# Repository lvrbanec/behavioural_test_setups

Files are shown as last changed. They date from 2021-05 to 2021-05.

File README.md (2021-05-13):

# Behavioural test setups

Behavioural tests setups created to test cognitive abilities of wild shrews (Sorex araneus).
Setups were modelled FreeCAD and automatized with Arduino and Raspberry Pi. 

Here I provide the 3D modells as well as the code.

** Half of the setups where created at the Max Planck Insitute (MPI) for Animal Behavior (Radolfzell, Germany) and therefore, belong to this insitution. For reuse of setup in research or industry please acquire consensus from MPI.

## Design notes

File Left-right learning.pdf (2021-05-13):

# Explanation of the left-right learning setup for testing cognitive abilities of common shrews (Sorex araneus)

### Author: Lara Vrbanec

### Date: 30.10.2020

# Contents

## Objective

The objective of the left- right learning setup is to test the spatial memory of the common shrew in the outside enclosure, without the disturbance of the experimenter. The animal is presented with two identical opaque tunnels, one of which always provides the food reward. The aim is to see how many trials animal needs to learn the rewarding arm, and how high is the mistake (how often the animal will sample the non-rewarding arm) after the learning objective is reached.

## Left right learning setup design

Setup consist of two identical opaque tunnels (1 x 10cm) connected to the automatic food dispenser. Every tube consists of two IR sensors, which record the direction of animal movement (entry / exit), and date and time of the activation. The information is saved as a .txt file on a SD card as ' sensor,1a,timestamp,[date].

## Tunnel design

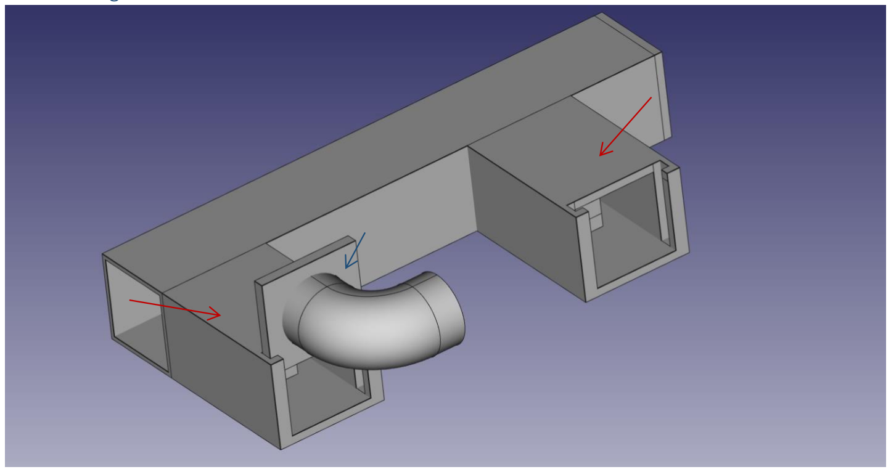
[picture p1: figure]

Figure 1. 3D model of the right / left tunnel created in software FreeCAD. Two constructions on the right marked with red arrows are used as IR sensor holders, and for the stabilization of the test setup. The lid, marked with blue arrow is used to prevent the moisture from entering the setup as the setup is intended for use in outdoor conditions.

## Automatic food dispenser design

The dispenser consists of thee parts (i) body that holds the mealworms (ii) casing and (iii) lid. The body is intended to connect to the NEMA-17 size stepper motor, which allows for the rotation of the dispenser and the dispensing of mealworms due to the gravity.

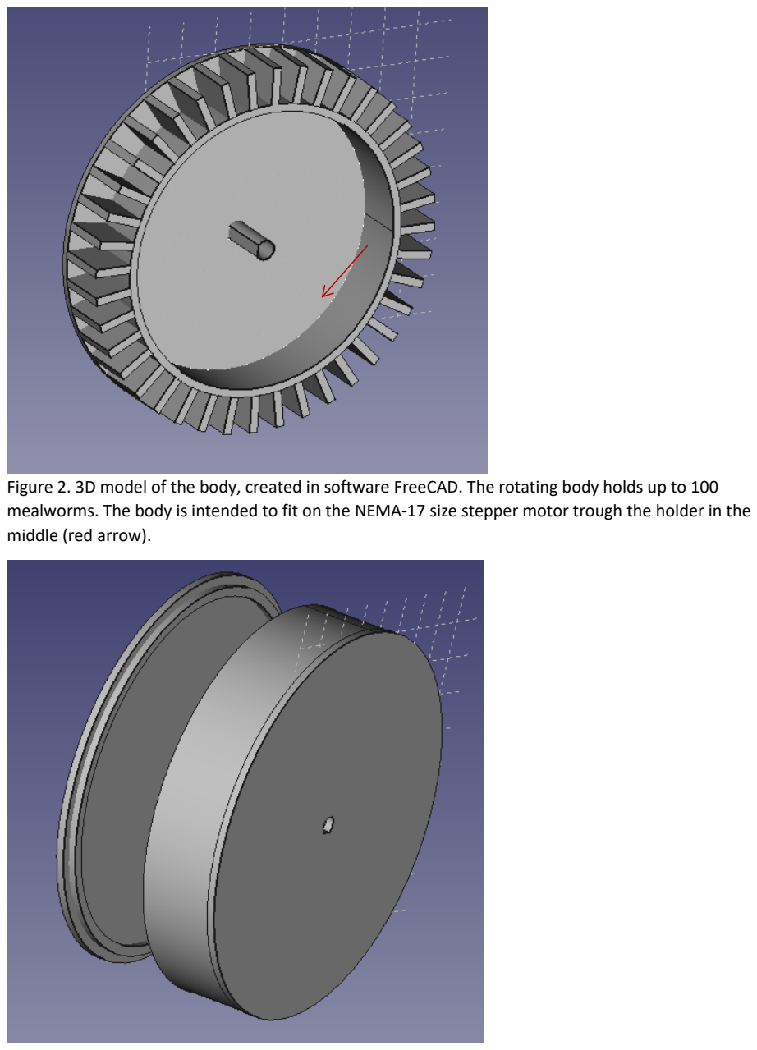
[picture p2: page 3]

Figure 2. 3D model of the body, created in software FreeCAD. The rotating body holds up to 100 mealworms. The body is intended to fit on the NEMA-17 size stepper motor trough the holder in the middle (red arrow).

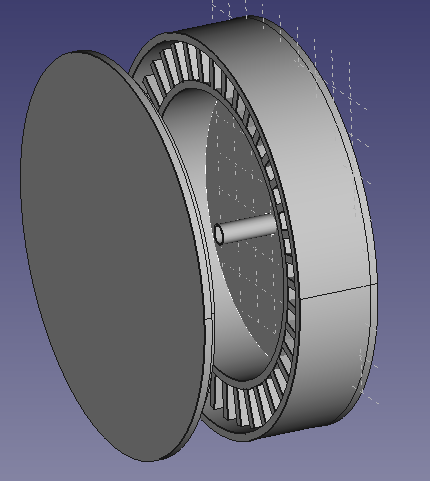
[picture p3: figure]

Figure 4. 3D model of the whole food dispenser, created in software FreeCAD.

## Electronics components and Supplies

### - 1x Arduino (we used Arduino Uno)

### - 1x Adafruit Motor Shield V2

### - 4x obstacle avoidance IR sensors (we used Waveshare)

### - 1x stepper motor (we used NEMA-17 size - 200 steps/rev, 12V 350mA)

### - RTC for Arduino (we used tiny RTC I2C module)

### - Micro SD card module

### - Bread board

### - Jumper cables

- Power source for Arduino (we used 12V/5A) and for Raspberry Pi (we used official SUB charger 5.1V 3A)

### - micro SD card

## Schematics

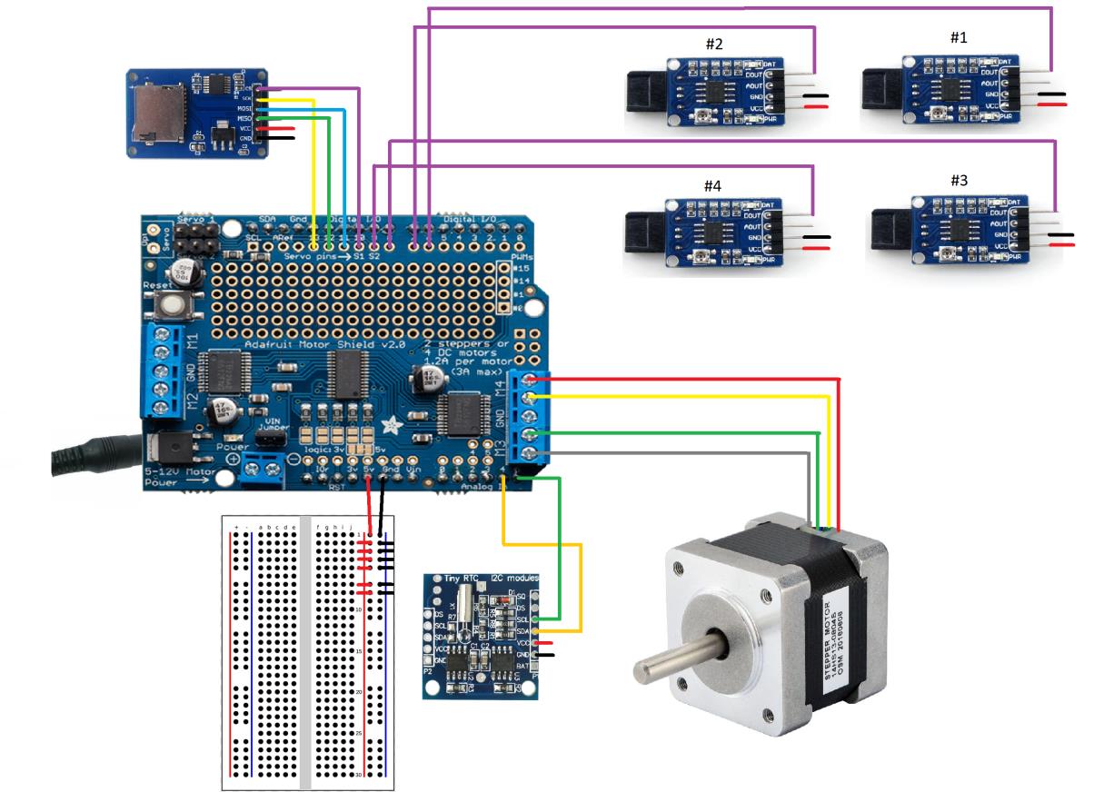
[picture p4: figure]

## Arduino code

When the animal enters the tunnel (sensor2 activated after sensor1) the motor dispenses the food and saves the unix time of animal entrance on the SD card.

// OS Windows 10, Arduino 1.8.10

// Author Lara Vrbanec

// Date 06/04/2020

// code sources SD_card https://lastminuteengineers.com/arduino-microsd-card-module-tutorial/ RTC https://lastminuteengineers.com/ds1307-rtc-arduino-tutorial/

// sensors Waveshare_IR_sensor MicroSD_card_adapter Tiny_RTC_12C_module(DS1307)

// When IR sensor1 is activated after IR sensor2, the motor is rotated and the unix time is saved on a micro SD card

// When IR sensor3 is activated after IR sensor4, the unix time is saved on SD card

#include <SPI.h> | // library for SPI SD

#include <SD.h> | // library for SD

#include <Wire.h> // library for RTC

#include "RTClib.h" // library RTClib by Adafruit for RTC

#include <Adafruit_MotorShield.h> // library for Adafruit motor shield v2

#define ledPin 4

#define motor 2

#define IR1 6

#define IR2 7

#define IR3 8

#define IR4 9

RTC_DS1307 rtc;

File myFile; // name of a file to be saved

Adafruit_MotorShield AFMS = Adafruit_MotorShield(); // Create the motor shield object with the default I2C address

Adafruit_StepperMotor *Motor = AFMS.getStepper(200, motor); // Connect a stepper North with 200 steps per revolution (1.8 degree) to motor port #2 (M3 and M4)

const int chipSelect = 10; // SD of SD card module. Other SD pins are pre-defined

const int OneMotorRotation = 15; // define n degrees by which the motor will move

boolean seq1 = false; // used to create a sequence of sensors

boolean seq2 = false; // used to create a sequence of sensors

// blink out an error code (number of blinks equal the error number)

void error(uint8_t errno) {

while(1) {

uint8_t i;

for (i=0; i<errno; i++) {

digitalWrite(ledPin, HIGH);

delay(100);

digitalWrite(ledPin, LOW);

delay(100);

}

for (i=errno; i<10; i++) {

delay(200);

}

}

}

void setup()

{

// Open serial communications

Serial.begin(9600);

// create with the default frequency 1.6KHz for motor shield

AFMS.begin();

// Define IR sensor imput (digital)

pinMode(IR1,INPUT); //

pinMode(IR2,INPUT); //

pinMode(IR3,INPUT); //

pinMode(IR4,INPUT); //

// Set speed of motor

Motor -> setSpeed(20); // 10 rpm

// Check if SD card started normally

Serial.print("Initializing SD card...");

if (!SD.begin()) {

Serial.println("initialization failed!");

error(1);

return;

}

Serial.println("initialization done.");

// Create a filename on SD when Arduino re-starts

char filename[15]; //create a filename with 15 characters

strcpy(filename, "TRC00.TXT");

for (uint8_t i = 0; i < 100; i++) {

filename[3] = '0' + i/10;

filename[4] = '0' + i%10;

if (! SD.exists(filename)) {

// only open a new file if it doesn't exist

myFile = SD.open(filename, FILE_WRITE);

// write if it cannot open the SD

if( ! myFile ) {

Serial.print("Couldnt create ");

Serial.println(filename);

error(2);

return; //try again the loop

}

Serial.print("Opened ");

Serial.println(filename);

break; // leave the loop!

}

}

// Check if RTC started normally

Serial.print("Initializing RTC...");

if (! rtc.begin()) {

Serial.println("Couldn't find RTC");

error(3);

while (1);

}

if (!rtc.isrunning()) {

Serial.println("RTC lost power, lets set the time!");

// Comment out below lines once you set the date & time.

// Following line sets the RTC to the date & time this sketch was compiled

// rtc.adjust(DateTime(F(__DATE__), F(__TIME__))); //uncomment if you want to set the time

// Following line sets the RTC with an explicit date & time

// for example to set January 27 2017 at 12:56 you would call:

// rtc.adjust(DateTime(2017, 1, 27, 12, 56, 0));

}

Serial.println("initialization done.");

}

void loop()

{

//if the animal choses correct side

if (digitalRead(IR1)==0) {

seq1 = true;

Serial.println("Sensor IR1 detected movement");

}

if (seq1 == true && digitalRead(IR2)==0) { // if BOTH

Serial.println("Sensor IR2 detected movement after IR1");

// move motor

Motor->step(OneMotorRotation, FORWARD , SINGLE); // 50 is 90 degrees as the motor has 200 steps

// get the unix time

DateTime currentTime = rtc.now();

// if the file opened okay, write to it:

if (myFile) {

Serial.println("writing to txt file...");

myFile.print("Choice,true,"); myFile.print("Timestamp,");

myFile.println(currentTime.unixtime()); //write to SD

myFile.flush(); // without .flush nothing can be printed on a card

}

if (! myFile) {

error(4);

return;

}

seq1 = false;

}

//if the animal choses wrong side

if (digitalRead(IR3)==0) {

seq2 = true;

Serial.println("Sensor IR3 detected movement");

}

if (seq2 == true && digitalRead(IR4)==0) { // if BOTH

Serial.println("Sensor IR4 detected movement after IR3");

// get the unix time

DateTime currentTime = rtc.now();

// if the file opened okay, write to it:

if (myFile) {

Serial.println("writing to txt file...");

myFile.print("Choice,false,"); myFile.print("Timestamp,");

myFile.println(currentTime.unixtime()); //write to SD

myFile.flush(); // without .flush nothing can be printed on a card

}

if (! myFile) {

error(4);

return;

}

seq2 = false;

}

}

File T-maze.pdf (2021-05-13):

# Guidance for using automated multiple T maze designed to test cognitive abilities of common shrews (Sorex araneus)

Owner: Max Planck Institute for Animal Behavior

Author: Lara Vrbanec

Date: 19.05.2020

## Contents

### Objective

The aim of the multiple T maze is to test common shrews’ navigation abilities related to foraging. The animal which makes less mistakes to learn the path which leads to a food reward is considered to be superior in navigation.

### Multiple T maze design

Maze arms are built from the opaque grey plastics and covered by the transparent Plexiglas®. The dimension of each arm was 100 x 5 x 5 cm (length, with, height). The maze can be placed into two configurations which are the left - right mirror images of each other. In the first configuration the animal has to perform the sequence of R, L, L, R, R, L turns to escape the maze. In the second configuration has to perform the sequence of L, R, R, L, L, R turns to escape the maze.
As our goal is to test animal’s navigation abilities related to foraging, the escaping arm is reinforced with a food reward. In order to simulate natural environment, maze floor is covered with the white sand. The entrance and the goal arm of the maze is connected with the home cage with transparent tubes. The setup includes two automatic doors and one automatic food dispenser. The first automatic door (in the following text referred to as the South door) is placed at the entrance of the maze. The second door (in the following text referred to as the North door) is placed 20 cm in front the food reward. First pair of movement sensors (in the following text referred to as the South sensor) are placed few centimeters behind the South door. The second pair of movement sensors (in the following text referred to as the North sensors) are placed few centimeters being the North door. The automatic feeder is positioned at the end of the goal arm and is used for automatic refill of food award.

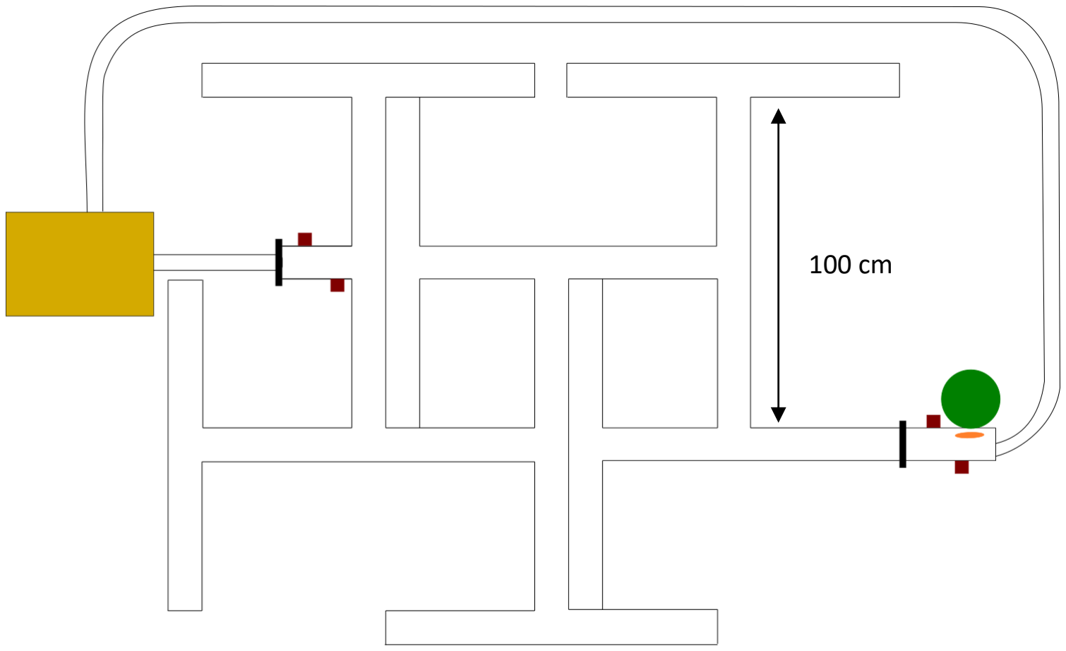
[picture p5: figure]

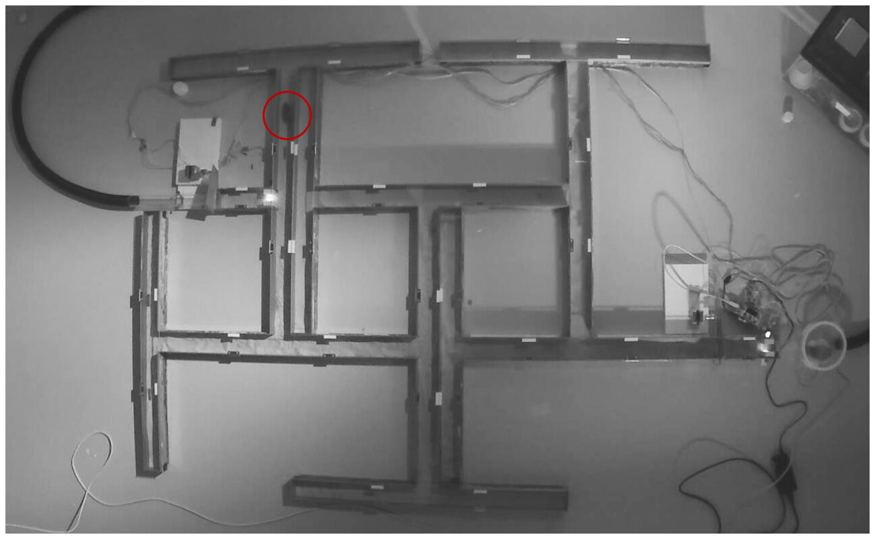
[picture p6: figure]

Figure 2. Upper image: Schematic of the multiple T maze in the first configuration (R, L, L, R, R, L ). Home cage is shown in yellow, automatic doors in black, movement sensors in red, automatic food dispenser in green, and food reward (mealworm) in orange. Lower image: multiple T maze under low light, recorded with IR camera. The position of the animal is shown with the red circle.

Automatic doors design
A stepper motor arm was prolonged with a screw over motor coupling. Onto prolonged arm, using two mothers, we attached an opaque Plexiglas sheet (2mm thickness, 15 cm length, 7 cm height). Rotation of the motor arm caused rotation of the Plexiglas sheet.

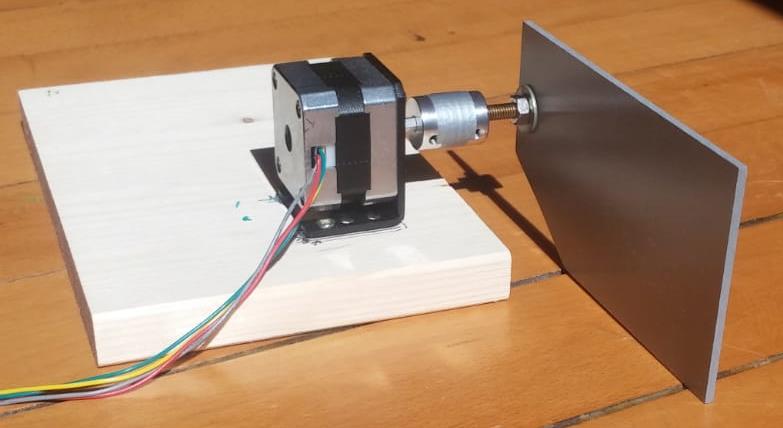
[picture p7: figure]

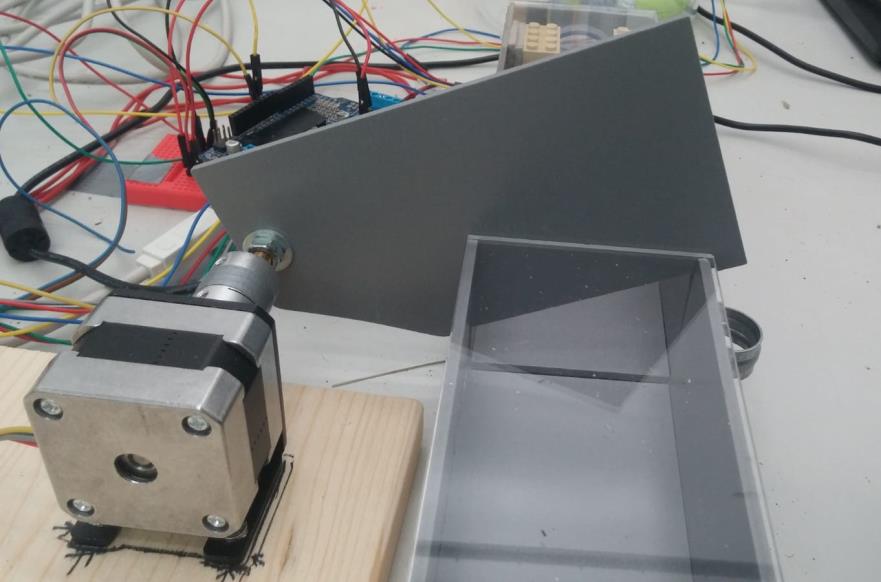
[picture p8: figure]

Figure 3. Automatic doors.

Automatic food dispenser design
Automatic food dispenser was built from the manual pill dispenser (example of a pill dispenser https://www.amazon.co.uk/Aidapt-Compact-Weekday-Dispenser-Eligible/dp/B0079N7L8U) by replacing the mechanism for manual rotation with a stepper motor.

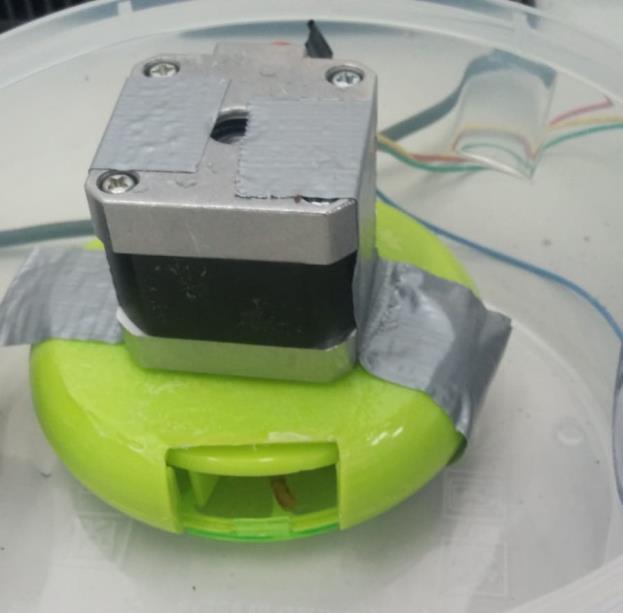
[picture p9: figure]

Figure 4. Automatic food dispenser

IR movement sensors design

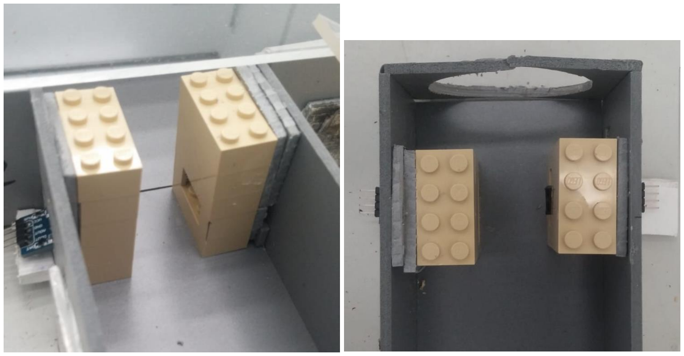
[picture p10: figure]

Figure 5. IR movement sensors placed at the beginning and the end of the labyrinth. The structure is L-R symmetrical so the animal cannot use sensor as cue for orientation.

### The logic behind the code

When the Arduino Uno reboots, the South doors open, which allows animal to enter the multiple T maze. Animal’s entrance in the multiple T maze triggers the South IR movement sensor, which causes automatic feeder to drop the food and the North door to open. When the animal enters the goal arm of the maze and triggers North IR movement sensor, both the North and the South door close. Closing North doors prevents animal from returning to the maze from the opposite direction, and closing the South doors prevents the animal from re-entering the maze immediately after it consumed the food reward. Both doors were closed for 20 minutes. The previous research has shown that common shrews increase their exploration tendencies if when less food deprived. Therefore, we prevented animal from entering the multiple T maze for 20 minutes after it consumed the food reward to avoid testing exploration and to focus on testing navigational abilities during food foraging. The South door automatically opens 20 minutes after they were closed which allows animal to spontaneously enter the multiple T maze from the start arm, which starts the next trial.

In order to track the progress of the experiment without physically being present in the experimental room, following animal’s actions trigger the receiving of email notifications.
1) Each time the animal solves the experiment (when it triggers the South IR movement sensor), a message ‘Animal has solved the experiment’ is received. This email helps the experimenter track the number of trials the animal has conducted.
2) If the animal did not consume food for one hour (if time between consecutive triggering the North IR movement equals 60 minutes or longer), a message ‘Animal is starving’ is received. This action should warn the experimenter to interfere with the experiment and feed the animal.

### Electronics components and Supplies

- 1x Arduino (we used Arduino Uno)
- 1x Raspberry Pi (we used Raspberry Pi 4, 2GB RAM)
- 2x Adafruit Motor Shield V2

second shield needs to be adapted as in instructions on Adafruit https://learn.adafruit.com/adafruit-motor-shield-v2-for-arduino/stacking-shields

- 2x obstacle avoidance IR sensors (we used Waveshare)
- 3x stepper motor (we used NEMA-17 size - 200 steps/rev, 12V 350mA)
your motor shield needs to be compatible with the power of stepper motors
- Bread board
- Jumper cables
- Power source for Arduino (we used 12V/5A) and for Raspberry Pi (we used official SUB charger 5.1V 3A)
- USB 2.0 cable for connecting Arduino to Raspberry Pi with serial connection
- Ethernet shield and Ethernet connection / WIFI connection for Raspberry Pi

### Schematics

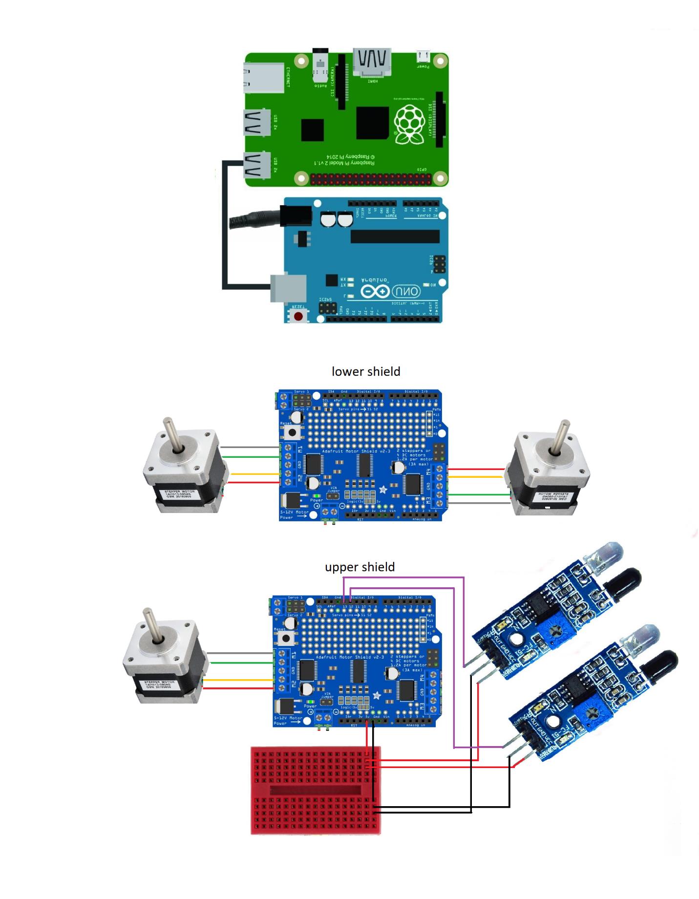
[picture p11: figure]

### Code

Arduino and Raspberry Pi communicate over serial connection. Arduino is used to move motors when the IR sensors are triggered, and Raspberry Pi is used to send emails to the user.

Arduino
Prior to uploading the code to Arduino change:

int starvingT = 30; // define starving time (in ms). If the animal did not eat for this time, you will receive email notification

int waitingT = 30; // define waiting time (in ms). This is waiting time between two trials in which the animal cannot enter the maze (both doors closed)

Current values are used for checking the functionality of the setup!

// OS Windows 10, Arduino 1.8.10

// Author Lara Vrbanec

// Date 14/04/2020

// code sources Adafruit_motor_shield_v2 https://learn.adafruit.com/adafruit-motor-shield-v2-for-arduino/stacking-shields

// sensors Waveshare_IR_sensor Adafruit_motor_shield_v2 Adafruit_StepperMotor

#include <Wire.h>

#include <Adafruit_MotorShield.h> // library for Adafruit_motor_shield_v2

// Create the motor shield object with the default I2C address

Adafruit_MotorShield AFMS1 = Adafruit_MotorShield(0x60);

// Create the motor shield on top of the AFMS1

Adafruit_MotorShield AFMS2 = Adafruit_MotorShield(0x61);

// Connect a stepper North with 200 steps per revolution (1.8 degree) to motor port #2 (M1 and M2)

Adafruit_StepperMotor *MotorNorth = AFMS1.getStepper(200, 1);

// Connect a stepper South with 200 steps per revolution (1.8 degree) to motor port #2 (M3 and M4)

Adafruit_StepperMotor *MotorSouth = AFMS1.getStepper(200, 2);

// Connect a stepper Feeder with 200 steps per revolution (1.8 degree) to motor port #2 (M1 and M2)

Adafruit_StepperMotor *MotorFeeder = AFMS2.getStepper(200, 1);

#define ledPin 4 // for visualizing error

#define IRNorth 11 // changed to pin 11 as pin 13 is not working!

#define IRSouth 12 // IR sensor to pin 12

unsigned long Time1 = 0;

unsigned long Time2 = 0;

unsigned long TimeDifference = 0;

int count = 0; // execute the function only once

int starvingT = 30; // define starving time (in ms). If the animal did not eat for this time, you will receive email notification

int waitingT = 30; // define waiting time (in ms). This is waiting time between two trials in which the animal cannot enter the maze (both doors closed)

// blink out an error code (number of blinks equal the error number)

void error(uint8_t errno) {

while(1) {

uint8_t i;

for (i=0; i<errno; i++) {

digitalWrite(ledPin, HIGH);

delay(100);

digitalWrite(ledPin, LOW);

delay(100);

}

for (i=errno; i<10; i++) {

delay(200);

}

}

}

void setup() {

// Define IR sensor imput (digital)

pinMode(IRNorth,INPUT);

pinMode(IRSouth,INPUT);

Serial.begin(9600); | // set up Serial library at 9600 bps
AFMS1.begin(); | // create with the default frequency 1.6KHz
AFMS2.begin(); | // create with the default frequency 1.6KHz
MotorNorth->setSpeed(10); | // 10 rpm
MotorSouth->setSpeed(10); | // 10 rpm

MotorFeeder->setSpeed(10); // 10 rpm

}

void loop() {

//when booted, move motorSouth up

if(count == 0) //

{

MotorSouth->step(12, FORWARD, SINGLE); // 50 is 90 degrees as the motor has 200 steps

count = 1; //if executed, do not repeat

}

else{

}

//Serial.println(count); //for troubleshooting

//when IRSouth activated, move motorNorth up and Feeder once

if(digitalRead(IRSouth)==0 && count == 1 ) // digitalRead == 0 (circuit grounded) when the sensor is active

{

MotorNorth->step(12, FORWARD, SINGLE); // 50 is 90 degrees as the motor has 200 steps

MotorFeeder->step(54, BACKWARD , SINGLE); // drop the food

count = 2; //if executed, do not repeat

}

else{

}

Serial.println(count); //for troubleshooting

//Serial.println(digitalRead(IRNorth)); //for troubleshooting

//when IRNorth activated, move motorNorth down and motorSouth down. After 20 min move motorSouth up.

if(digitalRead(IRNorth)==0 && count == 2 ) // digitalRead == 0 (circuit open) when the sensor is active

{

Serial.println("IRNorth activated"); // send message to Raspberry Pi when IRNorth is activated

Time2 = millis(); // Time1, Time1 and TimeDifference used to calculate ms elapsed between two activations of IRNorth

TimeDifference = Time2 - Time1;

if(TimeDifference > starvingT) { //3600000 is 1h

Serial.println("Animal did not eat for 1h!"); // send message to Raspberry Pi

}

Serial.print("Time difference between activating IRNorth is: "); Serial.print (TimeDifference); Serial.println (" ms");

MotorNorth->step(12, BACKWARD, SINGLE); // 50 is 90 degrees as the motor has 200 steps

MotorSouth->step(12, BACKWARD, SINGLE); // 50 is 90 degrees as the motor has 200 steps

Time1 = millis();

delay(waitingT); // wait, 1200000 ms is 20 min

MotorSouth->step(12, FORWARD, SINGLE); // 50 is 90 degrees as the motor has 200 steps

count = 1; //if executed, wait for IRSouth to get activated

}

else{

}

}
Raspberry pi
// OS Windows 10, Arduino 1.8.10

// Author Lara Vrbanec

// Date 14/04/2020

// code sources Adafruit_motor_shield_v2 https://learn.adafruit.com/adafruit-motor-shield-v2-for-arduino/stacking-shields

// sensors Waveshare_IR_sensor Adafruit_motor_shield_v2 Adafruit_StepperMotor

#include <Wire.h>

#include <Adafruit_MotorShield.h> // library for Adafruit_motor_shield_v2

// Create the motor shield object with the default I2C address

Adafruit_MotorShield AFMS1 = Adafruit_MotorShield(0x60);

// Create the motor shield on top of the AFMS1

Adafruit_MotorShield AFMS2 = Adafruit_MotorShield(0x61);

// Connect a stepper North with 200 steps per revolution (1.8 degree) to motor port #2 (M1 and M2)

Adafruit_StepperMotor *MotorNorth = AFMS1.getStepper(200, 1);

// Connect a stepper South with 200 steps per revolution (1.8 degree) to motor port #2 (M3 and M4)

Adafruit_StepperMotor *MotorSouth = AFMS1.getStepper(200, 2);

// Connect a stepper Feeder with 200 steps per revolution (1.8 degree) to motor port #2 (M1 and M2)

Adafruit_StepperMotor *MotorFeeder = AFMS2.getStepper(200, 1);

#define ledPin 4 // for visualizing error

#define IRNorth 13 // IR sensor to pin 13

#define IRSouth 12 // IR sensor to pin 12

unsigned long Time1 = 0;

unsigned long Time2 = 0;

unsigned long TimeDifference = 0;

int count = 0; // execute the function only once

// blink out an error code (number of blinks equal the error number)

void error(uint8_t errno) {

while(1) {

uint8_t i;

for (i=0; i<errno; i++) {

digitalWrite(ledPin, HIGH);

delay(100);

digitalWrite(ledPin, LOW);

delay(100);

}

for (i=errno; i<10; i++) {

delay(200);

}

}

}

void setup() {

// Define IR sensor imput (digital)

pinMode(IRNorth,INPUT);

pinMode(IRSouth,INPUT);

Serial.begin(9600); | // set up Serial library at 9600 bps
AFMS1.begin(); | // create with the default frequency 1.6KHz
MotorNorth->setSpeed(10); | // 10 rpm
MotorSouth->setSpeed(10); | // 10 rpm

MotorFeeder->setSpeed(10); // 10 rpm

}

void loop() {

//when booted, move motorSouth up

if(count == 0) //

{

MotorSouth->step(50, BACKWARD, SINGLE); // 50 is 90 degrees as the motor has 200 steps

count = 1; //if executed, do not repeat

}

else{

}

//when IRSouth activated, move motorNorth up and Feeder once !add feeder

if(digitalRead(IRSouth)==0 && count == 1 ) // digitalRead == 0 (circuit grounded) when the sensor is active

{

MotorNorth->step(50, BACKWARD, SINGLE); // 50 is 90 degrees as the motor has 200 steps

MotorFeeder->step(10, FORWARD, SINGLE); // drop the food

count = 2; //if executed, do not repeat

}

else{

}

//when IRNorth activated, move motorNorth down and motorSouth down. After 20 min move motorSouth up.

if(digitalRead(IRNorth)==0 && count == 2 ) // digitalRead == 0 (circuit open) when the sensor is active

{

Serial.println("IRNorth activated"); // send message to Raspberry Pi when IRNorth is activated

Time2 = millis(); // Time1, Time1 and TimeDifference used to calculate ms elapsed between two activations of IRNorth

TimeDifference = Time2 - Time1;

if(TimeDifference > 3600000) { //3600000 is 1h

Serial.println("Animal did not eat for 1h!"); // send message to Raspberry Pi

}

Serial.print("Time difference between activating IRNorth is: "); Serial.print (TimeDifference); Serial.println (" ms");

MotorNorth->step(50, FORWARD, SINGLE); // 50 is 90 degrees as the motor has 200 steps

MotorSouth->step(50, FORWARD, SINGLE); // 50 is 90 degrees as the motor has 200 steps

Time1 = millis();

delay(1200000); // wait, 1200000 ms is 20 min

MotorSouth->step(50, BACKWARD, SINGLE); // 50 is 90 degrees as the motor has 200 steps

count = 1; //if executed, wait for IRSouth to get activated

}

else{

}

}

### Procedure for animal testing

In order to test exploration related to food search, animal is prior to testing food deprived for two hours (Keicher, 2017). The testing is conducted in dim light (< 10 lux) as it is believed that shrews are the most active in dawn and twilight. The trial starts when the home cage is connected with the maze with a transparent tube.

Animals are tested in multiple T maze for 12 trials in a row, with maximum of 6 trials during a single day. If the animal does not participate in the trial within 1.5 h from the start of the experiment, it is returned to the outside enclosure. If this occurs for three days, animal is excluded from the experiment and marked as not participating. If the animal does not discover the goal arm within 1h, it gently chased to the home cage and provided a piece of mealworm. The sand is replaced between different subjects and maze walls are cleaned with disinfectant.

The trial starts when the animal voluntarily enters the maze from a home cage, which activates automatic food dispenser that provides a mealworm in the goal arm of the maze. The trial is over when the animal reaches the goal arm, after which the automatic doors are closed and the animal is prevented from re-entering the maze for 20 min. After 20 min only the doors at the start of the maze open, preventing the animal to explore the maze from the goal arm. The next trial starts when the animal enters the start arm of the maze, which again activates the food dispenser and opens the doors at the goal end of the maze. Animal movement is tracked with the IR surveillance camera connected to the cloud storage over institute Ethernet.

### Analysis

Video recordings are analyzed with automatic tracking software to obtain animals’ movement coordinates. From the movement data we extract the number of wrong turns for each of the trials, the total distance covered during a single trial, and the time spent active in the maze during a single trial, as well as the sequence of turns (e.g. L L L R R …) for the first trial.

The number of wrong turns over multiple trials, total distance covered over multiple trials, and the time spent actively exploring the maze over multiple trials are used to a design learning curves.
The sequence of turns during the first trial is used as a proxy for non-cognitive strategy and is compared to the results of non- cognitive strategy obtained in a Y maze.

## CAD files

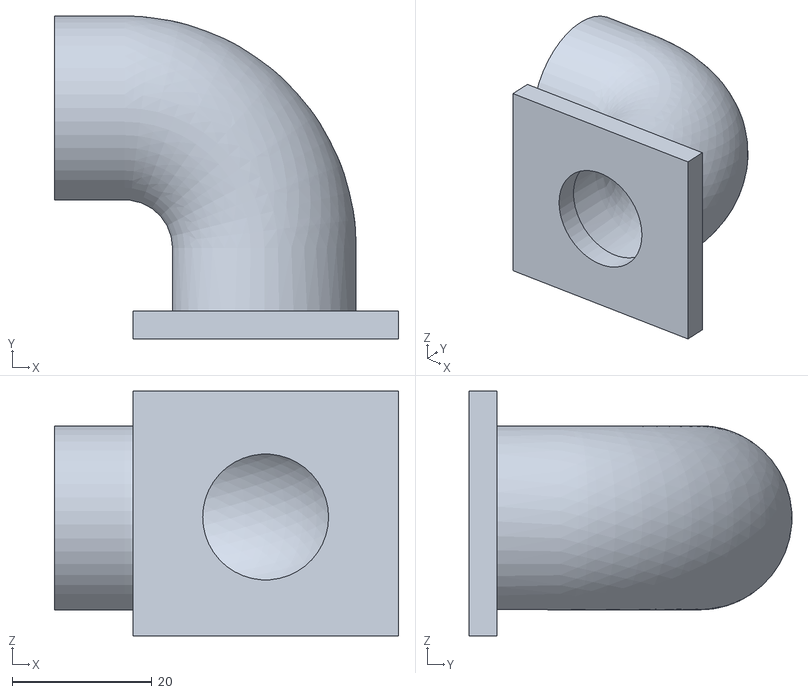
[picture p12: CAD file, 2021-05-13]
Left-right learning/lid.stl
49.2 x 46.1 x 35.0

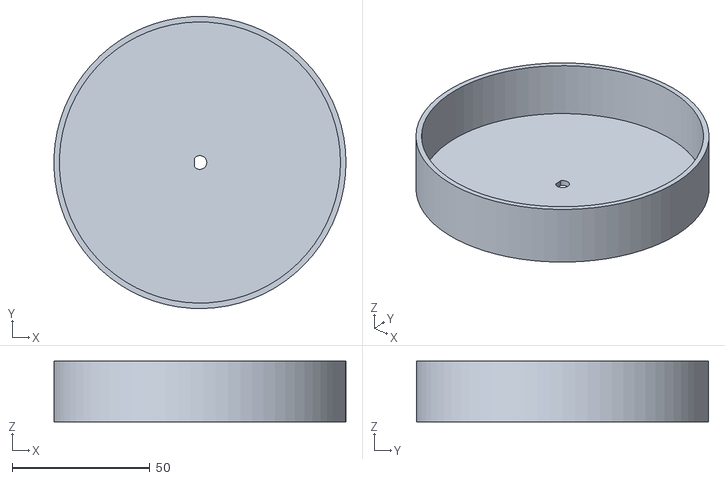
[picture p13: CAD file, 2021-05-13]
T-maze food dispenser 3D model/case.obj
106.0 x 106.0 x 22.0

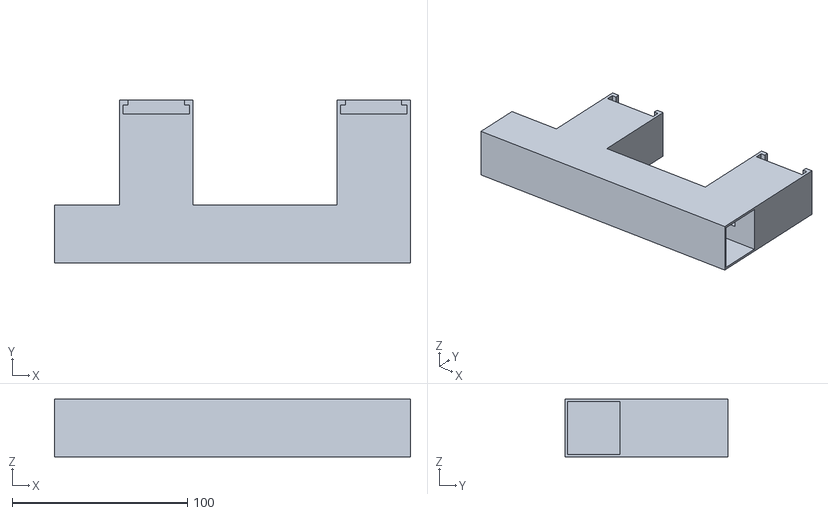
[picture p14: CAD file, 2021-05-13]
Left-right learning/body.stl
203.0 x 93.0 x 33.0

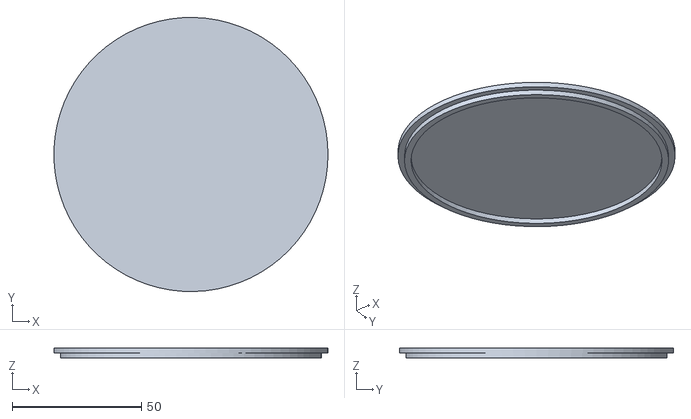
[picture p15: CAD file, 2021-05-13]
T-maze food dispenser 3D model/lid.obj
106.0 x 106.0 x 4.00

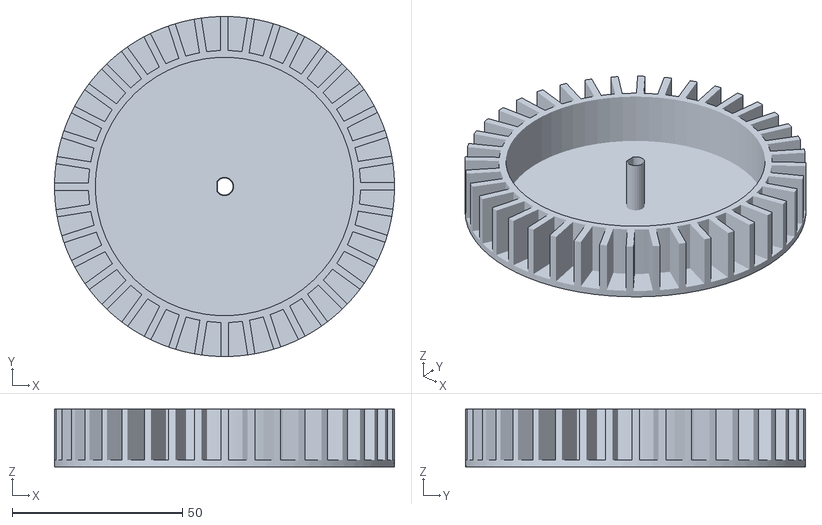
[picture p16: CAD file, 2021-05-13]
T-maze food dispenser 3D model/inside.obj
100.0 x 100.0 x 17.0
